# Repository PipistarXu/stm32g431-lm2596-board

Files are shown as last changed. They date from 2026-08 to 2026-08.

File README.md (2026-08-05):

# STM32G431 + LM2596 Custom Board

## Project Status
- PCB design completed
- Assembly not started yet

## Goals
- Build a custom control/power board based on STM32G431.
- Use LM2596 buck stage for stable DC conversion.
- Complete bring-up with safe current-limited power-on.

## Confirmed Hardware Decisions
- MCU: **STM32G431** (UFQFPN48 package)
- Buck IC: **LM2596S-ADJ**
- Schottky diode: **1N5822**
  - Polarity rule: **K (stripe) -> SW**, **A -> GND**
- Inductor: **CDRH127/LDNP-330MC**
  - 33uH, 12x12mm footprint, height ~8mm
- Small capacitors (SMD): 0603, X7R preferred
- R4 package: 0402 (1005 Metric), value TBD by final schematic intent

## Current Risks / Open Items
- [ ] Verify D2 pad net with multimeter (must be SW/GND as expected)
- [ ] Confirm 8mm inductor height clearance with enclosure/mechanics
- [ ] Confirm 220uF capacitor package availability (6.3x5.4 may be tight)
- [ ] Finalize R4 resistance value
- [ ] Prepare first power-on with current limit (0.1A~0.2A)

## Repository Layout
- `docs/`: notes, checklist, images
- `hardware/kicad/`: source schematic + PCB
- `hardware/fabrication/`: gerber, drill, BOM, pick-and-place
- `hardware/datasheets/`: key PDFs
- `firmware/`: future STM32 firmware

## First Bring-Up (Summary)
1. Visual inspection (orientation, bridges, polarity)
2. Resistance checks (VIN-GND, 5V-GND/3V3-GND)
3. Power from bench supply with 0.1A current limit
4. Verify LM2596 output and thermal behavior
5. Increase current limit gradually

## Notes
- UFQFPN48 is difficult for hand soldering; hot-air and flux are strongly recommended.
- Always trust actual net connectivity + multimeter over silkscreen when conflict exists.

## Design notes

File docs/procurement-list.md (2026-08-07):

# Procurement List (Current Draft)

## 1) Core ICs
- STM32G431 (UFQFPN48 package)
- LM2596S-ADJ
- 1N5822 (Schottky diode, DO-201 class)

## 2) Power Inductor
- Selected: **CDRH127/LDNP-330MC** (33uH, 12x12mm, H~8mm)

## 3) Capacitors (from current design snapshot)
- C1: 100nF, 0603, X7R
- C2: 0.47uF, 0603, X7R
- C3: 47uF, SMD electrolytic, low ESR
- C4: 100nF, 0603, X7R
- C5: 10nF, 0603, X7R
- C6: 100nF, 0603, X7R
- C7: 100nF, 0603, X7R
- C8: 100uF, SMD electrolytic, low ESR
- C9: 220uF, SMD electrolytic, low ESR
- C10: 100nF, 0603, X7R

## 4) Resistors
- R4 package: 0402 (1005 Metric), resistance value TBD
- Suggest stocking common debug values:
  - 0Ω
  - 100Ω
  - 10kΩ

## 5) Recommended Tools / Consumables
- Flux pen / solder paste
- Hot-air station
- Fine tweezers
- Multimeter
- Bench power supply with current limiting
- Optional oscilloscope (ripple/SW waveform check)

## 6) Pending Procurement Decisions
- Final R4 value after schematic intent confirmation
- Final electrolytic voltage rating vs actual VIN
- C9 package upsize if 6.3x5.4 sourcing is limited

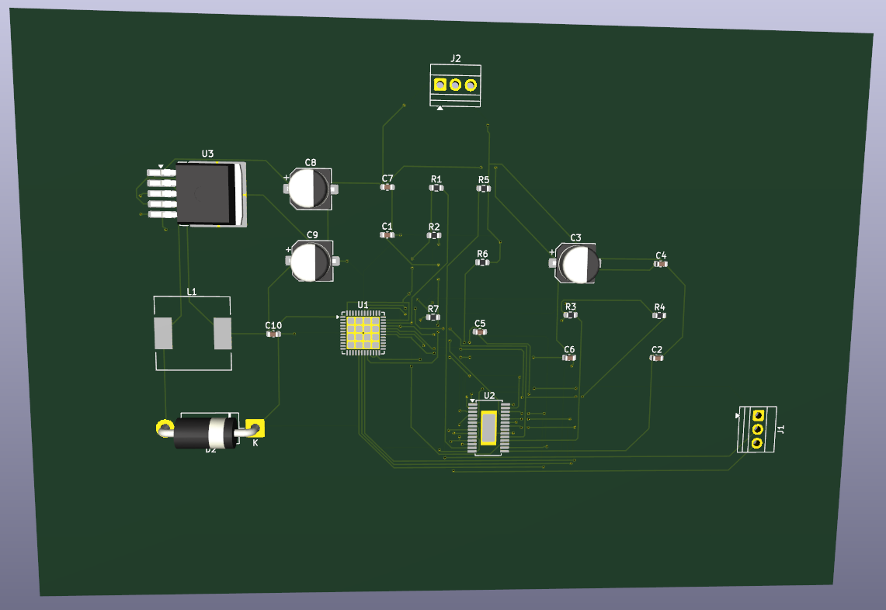
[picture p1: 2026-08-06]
docs/images/Screenshot 2026-08-05 223316.png

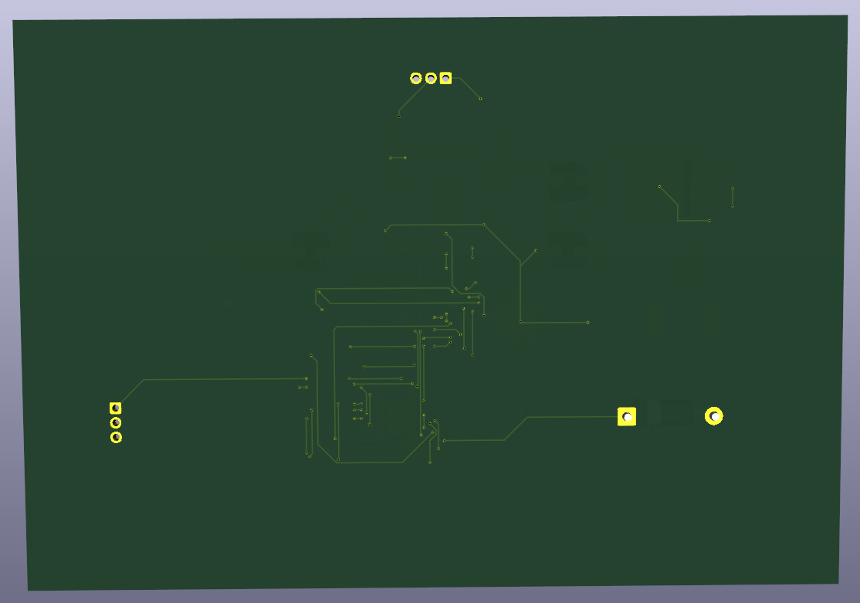
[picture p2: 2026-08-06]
docs/images/Screenshot 2026-08-05 223302.png

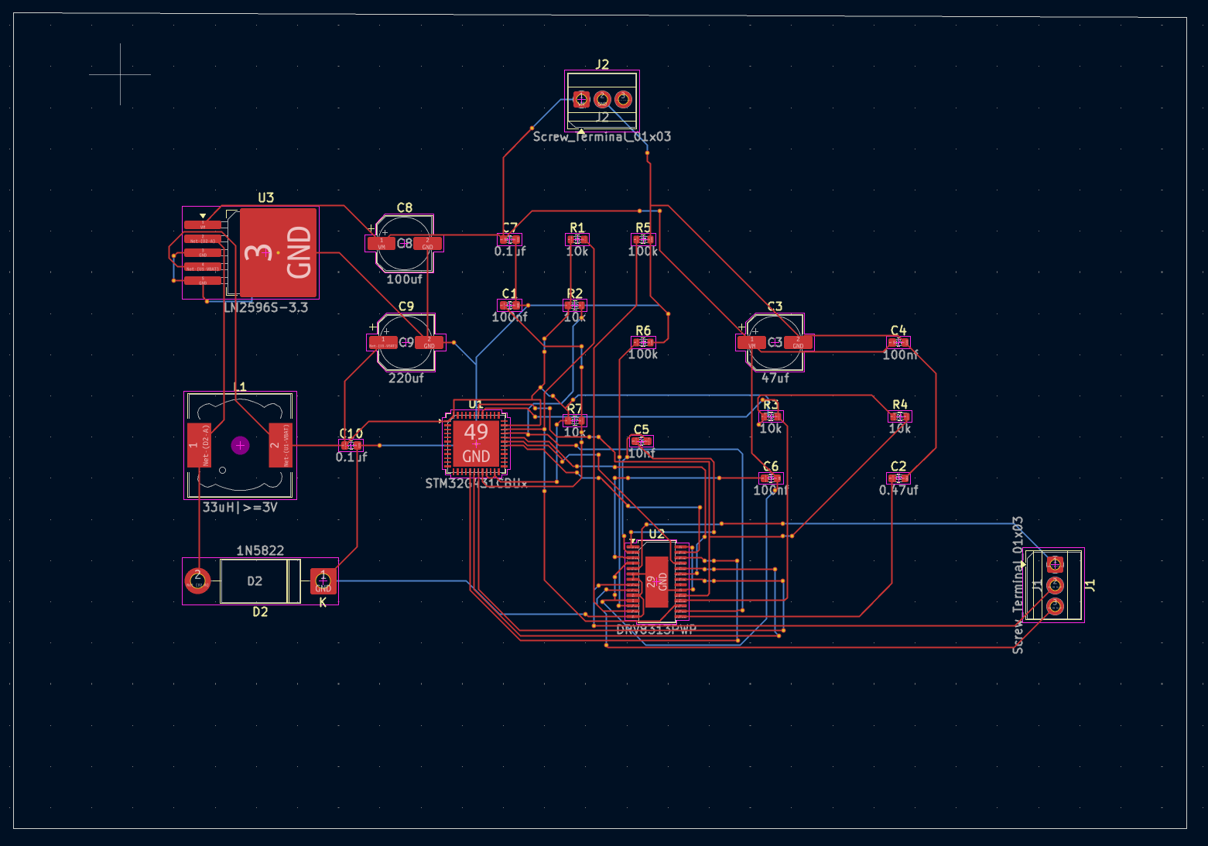
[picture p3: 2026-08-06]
docs/images/pcb_2d.png

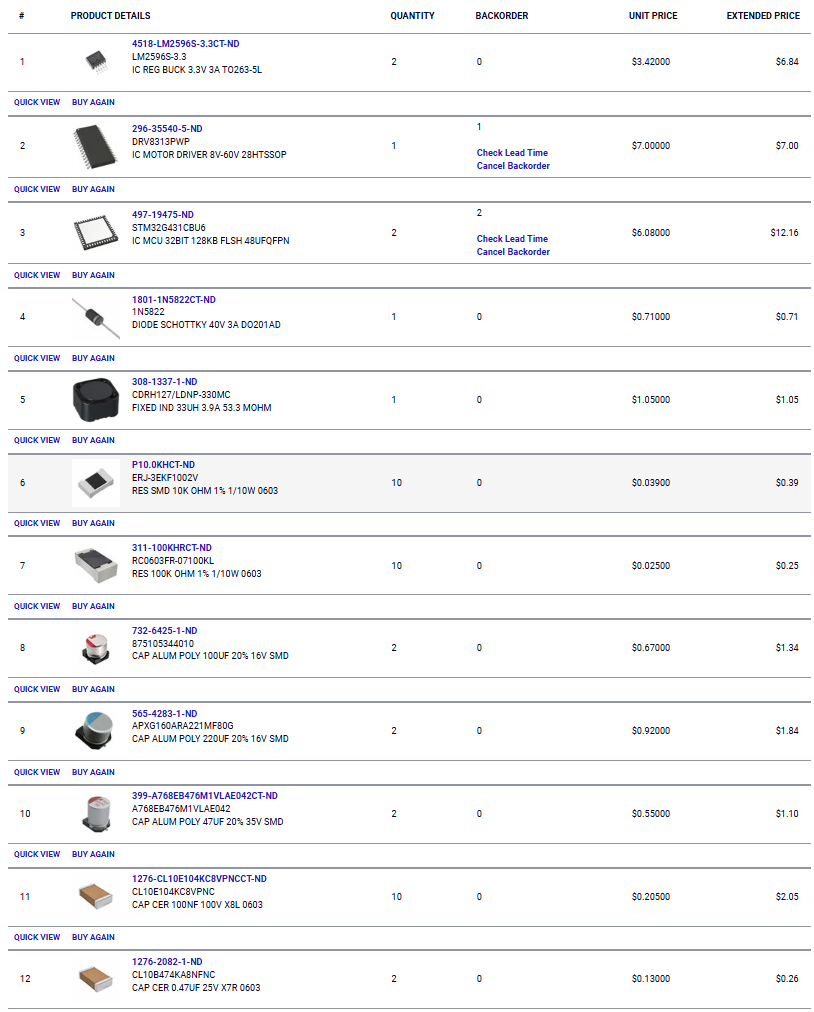
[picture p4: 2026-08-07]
docs/images/DigiKey_screenshot.png

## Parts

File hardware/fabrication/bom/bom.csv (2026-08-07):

Reference | Qty | Value | DNP | Exclude from BOM | Exclude from Board | Footprint | Datasheet | Check_prices | MANUFACTURER | MAXIMUM_PACKAGE_HEIGHT | MF | MP | Availability | Description | #
C1,C4,C6 | 3 | 100nf |  |  |  | Capacitor_SMD:C_0603_1608Metric |  |  |  |  |  |  |  | capacitor, US symbol | 1
C2 | 1 | 0.47uf |  |  |  | Capacitor_SMD:C_0603_1608Metric |  |  |  |  |  |  |  | capacitor, US symbol | 2
C3 | 1 | 47uf |  |  |  | Capacitor_SMD:CP_Elec_6.3x5.4 |  |  |  |  |  |  |  | capacitor, US symbol | 3
C5 | 1 | 10nf |  |  |  | Capacitor_SMD:C_0603_1608Metric |  |  |  |  |  |  |  | capacitor, US symbol | 4
C7,C10 | 2 | 0.1uf |  |  |  | Capacitor_SMD:C_0603_1608Metric |  |  |  |  |  |  |  | capacitor, US symbol | 5
C8 | 1 | 100uf |  |  |  | Capacitor_SMD:CP_Elec_6.3x5.4 |  |  |  |  |  |  |  | capacitor, US symbol | 6
C9 | 1 | 220uf |  |  |  | Capacitor_SMD:CP_Elec_6.3x5.4 |  |  |  |  |  |  |  | capacitor, US symbol | 7
D2 | 1 | 1N5822 |  |  |  | Diode_THT:D_DO-201AD_P15.24mm_Horizontal | http://www.vishay.com/docs/88526/1n5820.pdf |  |  |  |  |  |  | 40V 3A Schottky Barrier Rectifier Diode, DO-201AD | 8
J1,J2 | 2 | Screw_Terminal_01x03 |  |  |  | TerminalBlock:TerminalBlock_Xinya_XY308-2.54-3P_1x03_P2.54mm_Horizontal |  |  |  |  |  |  |  | Generic screw terminal, single row, 01x03, script generated (kicad-library-utils/schlib/autogen/connector/) | 9
L1 | 1 | 33uH|>=3V |  |  |  | Inductor_SMD:L_12x12mm_H6mm |  |  |  |  |  |  |  | Inductor | 10
R1,R2,R3,R4,R7 | 5 | 10k |  |  |  | Resistor_SMD:R_0603_1608Metric |  |  |  |  |  |  |  | Resistor | 11
R5,R6 | 2 | 100k |  |  |  | Resistor_SMD:R_0603_1608Metric |  |  |  |  |  |  |  | Resistor | 12
U1 | 1 | STM32G431CBUx |  |  |  | Package_DFN_QFN:QFN-48-1EP_7x7mm_P0.5mm_EP5.6x5.6mm | https://www.st.com/resource/en/datasheet/stm32g431cb.pdf |  |  |  |  |  |  | STMicroelectronics Arm Cortex-M4 MCU, 128KB flash, 32KB RAM, 170 MHz, 1.71-3.6V, 42 GPIO, UFQFPN48 | 13
U2 | 1 | DRV8313PWP |  |  |  | Package_SO:HTSSOP-28-1EP_4.4x9.7mm_P0.65mm_EP2.75x6.2mm |  | https://www.snapeda.com/parts/DRV8313PWP/Texas+Instruments/view-part/?ref=eda | Texas Instruments | 1.2 mm | Texas Instruments | DRV8313PWP | In Stock | 65-V max 3-A peak 3-phase motor driver with integrated FETs | 14
U3 | 1 | LM2596S-3.3 |  |  |  | Package_TO_SOT_SMD:TO-263-5_TabPin3 | http://www.ti.com/lit/ds/symlink/lm2596.pdf |  |  |  |  |  |  | 3.3V 3A Step-Down Voltage Regulator, TO-263 | 15

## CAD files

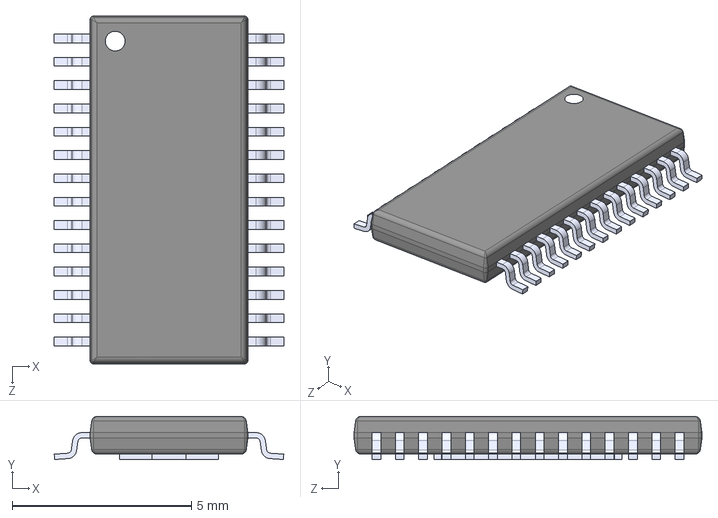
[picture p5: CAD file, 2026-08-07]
hardware/ kicad/ libraries/DRV8313PWP.step
6.40 x 1.20 x 9.70 mm

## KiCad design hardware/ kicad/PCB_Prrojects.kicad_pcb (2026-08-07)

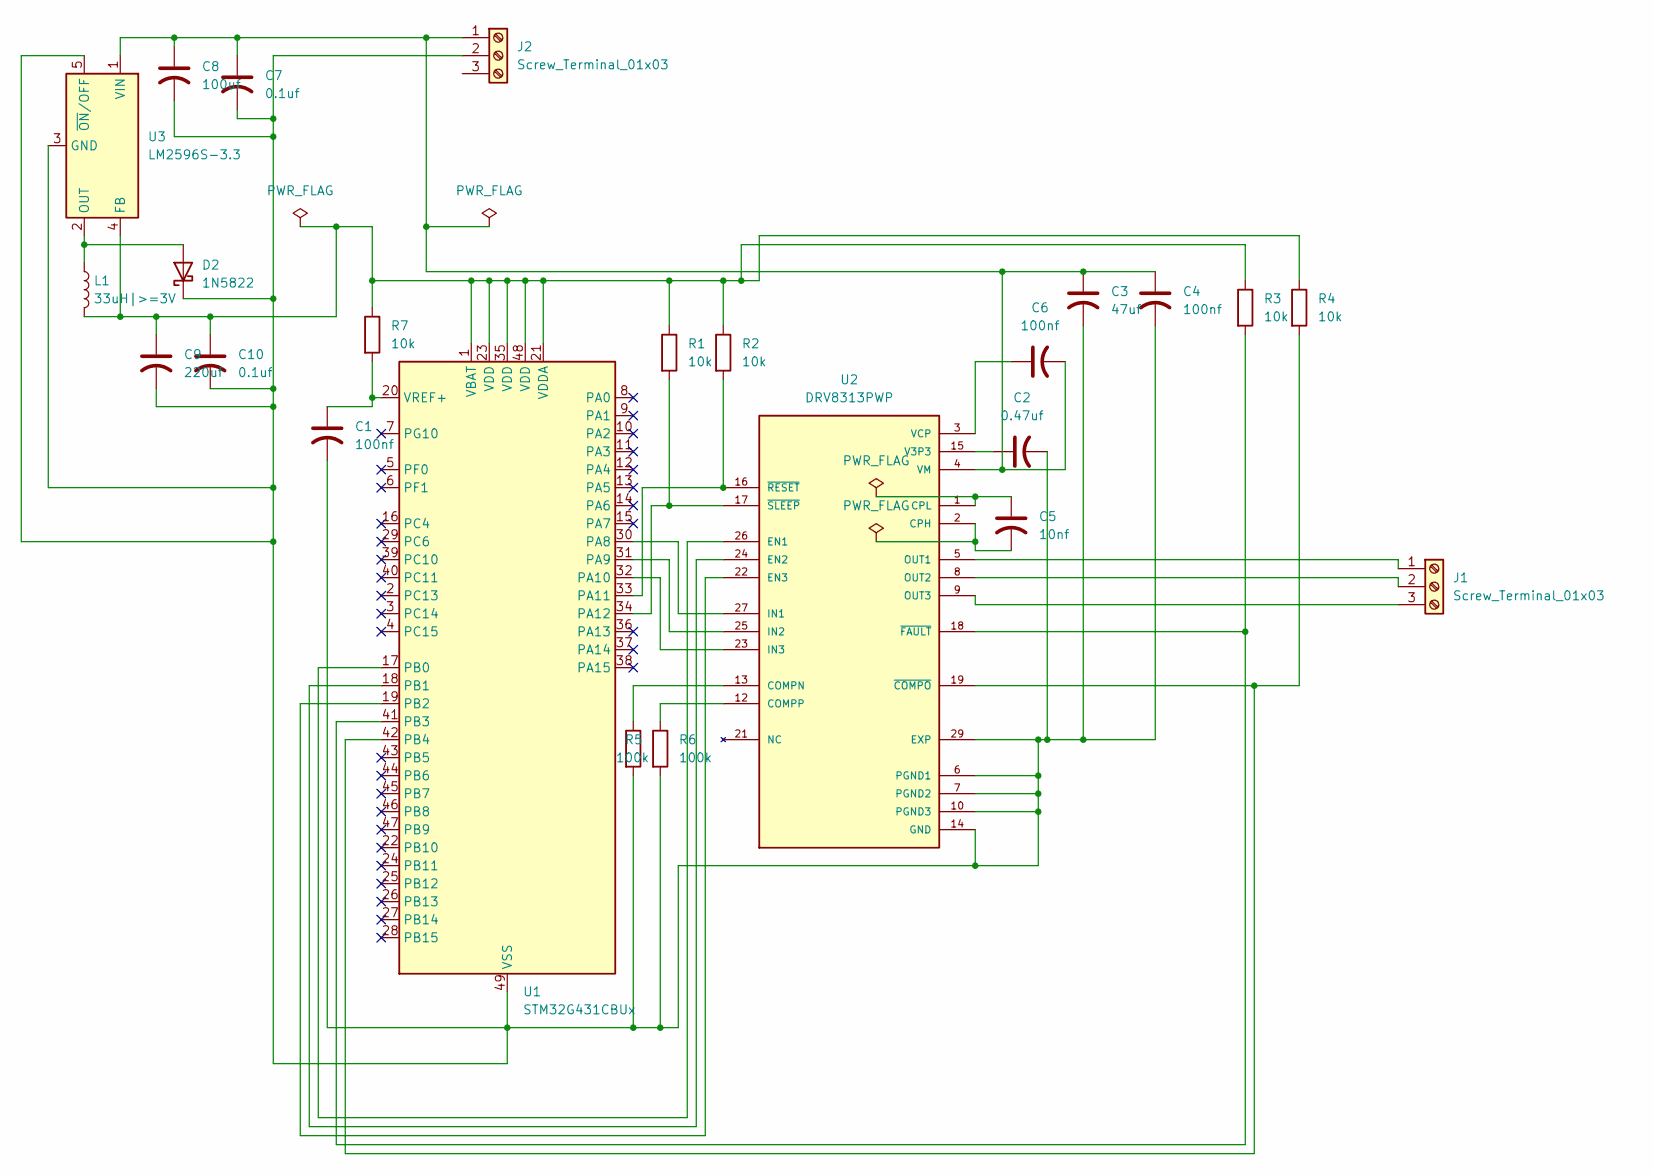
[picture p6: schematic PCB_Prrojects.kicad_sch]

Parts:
C1, C4, C6: 100nf; C_0603_1608Metric
C2: 0.47uf; C_0603_1608Metric
C3: 47uf; CP_Elec_6.3x5.4
C5: 10nf; C_0603_1608Metric
C7, C10: 0.1uf; C_0603_1608Metric
C8: 100uf; CP_Elec_6.3x5.4
C9: 220uf; CP_Elec_6.3x5.4
D2: 1N5822; D_DO-201AD_P15.24mm_Horizontal
J1, J2: Screw_Terminal_01x03; TerminalBlock_Xinya_XY308-2.54-3P_1x03_P2.54mm_Horizontal
L1: 33uH|>=3V; L_12x12mm_H6mm
R1, R2, R3, R4, R7: 10k; R_0603_1608Metric
R5, R6: 100k; R_0603_1608Metric
U1: STM32G431CBUx; QFN-48-1EP_7x7mm_P0.5mm_EP5.6x5.6mm
U2: DRV8313PWP; HTSSOP-28-1EP_4.4x9.7mm_P0.65mm_EP2.75x6.2mm; PARTREV D
U3: LM2596S-3.3; TO-263-5_TabPin3

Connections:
GND: C1.2, C2.2, C3.2, C4.2, C7.2, C8.2, C9.2, C10.2, D2.1 (K), J2.2, R5.2, R6.2, U1.49 (VSS), U2.6 (PGND1), U2.7 (PGND2), U2.10 (PGND3), U2.14 (GND), U2.20 (GND), U2.28 (GND), U2.29 (EXP), U3.3 (GND), U3.5 (~ON/OFF)
unnamed: D2.2 (A), L1.1, U3.2 (OUT)
unnamed: J1.1, U2.5 (OUT1)
unnamed: J1.2, U2.8 (OUT2)
unnamed: J1.3, U2.9 (OUT3)
unnamed: U1.30 (PA8), U2.27 (IN1)
unnamed: U1.31 (PA9), U2.25 (IN2)
unnamed: U1.32 (PA10), U2.23 (IN3)
unnamed: R2.2, U1.33 (PA11), U2.16 (~RESET)
unnamed: R1.2, U1.34 (PA12), U2.17 (~SLEEP)
unnamed: U1.17 (PB0), U2.26 (EN1)
unnamed: U1.18 (PB1), U2.24 (EN2)
unnamed: U1.19 (PB2), U2.22 (EN3)
unnamed: R3.2, U1.41 (PB3), U2.18 (~FAULT)
unnamed: R4.2, U1.42 (PB4), U2.19 (~COMPO)
unnamed: C9.1, C10.1, L1.2, R1.1, R2.1, R3.1, R4.1, R7.1, U1.1 (VBAT), U1.21 (VDDA), U1.23 (VDD), U1.35 (VDD), U1.48 (VDD), U3.4 (FB)
unnamed: C1.1, R7.2, U1.20 (VREF+)
unnamed: R5.1, U2.13 (COMPN)
unnamed: R6.1, U2.12 (COMPP)
unnamed: C5.2, U2.2 (CPH)
unnamed: C5.1, U2.1 (CPL)
unnamed: C2.1, U2.15 (V3P3)
unnamed: C6.1, U2.3 (VCP)
VM: C3.1, C4.1, C6.2, C7.1, C8.1, J2.1, U2.4 (VM), U2.11 (VM), U3.1 (VIN)

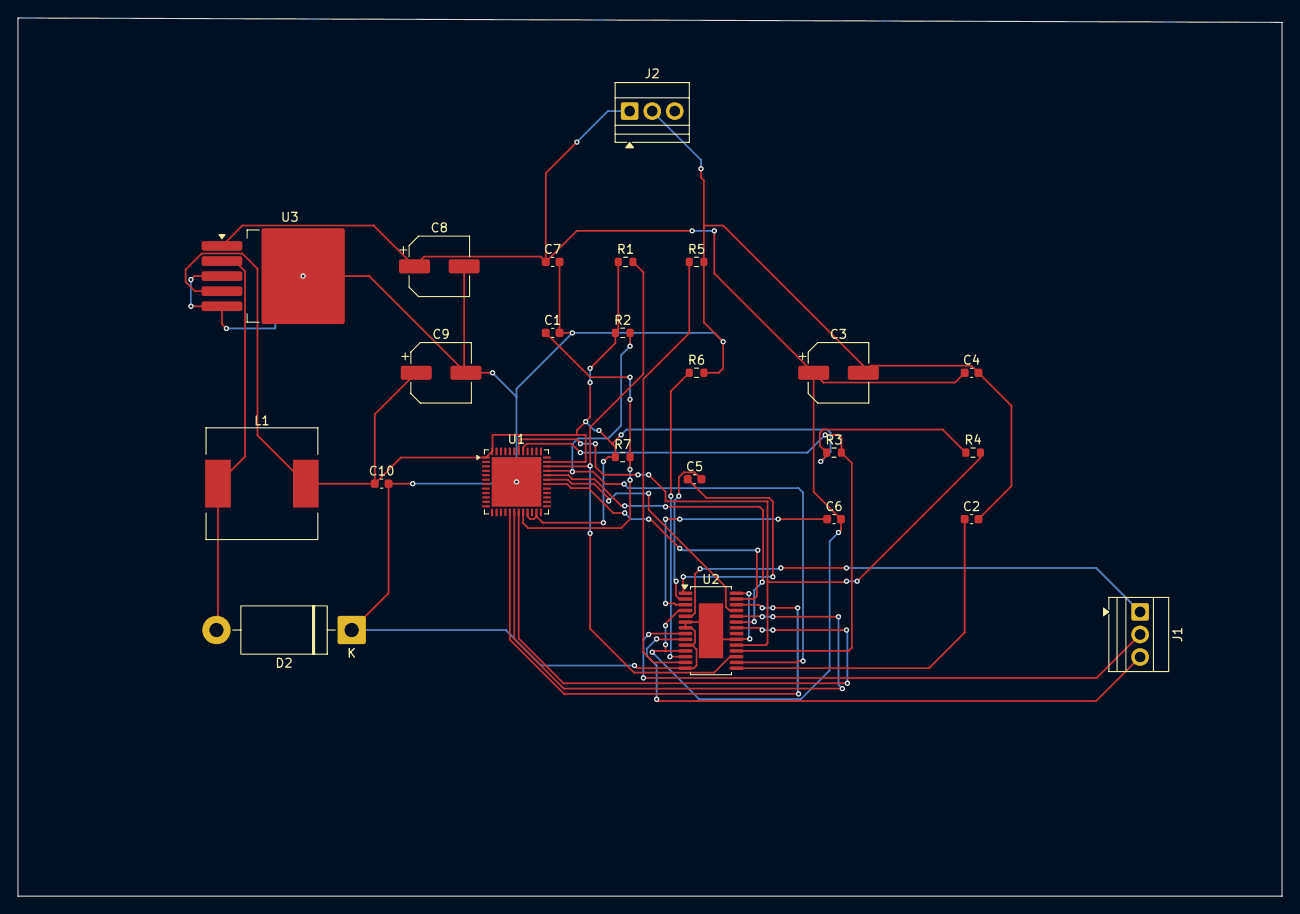
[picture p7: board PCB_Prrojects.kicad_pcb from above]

Board: 2 copper layers, 142.5 x 99.0 mm, 24 parts (0 on the bottom side), 24 nets.

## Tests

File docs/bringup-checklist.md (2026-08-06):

# Bring-Up Checklist (STM32G431 + LM2596)

## A. Pre-Solder Checklist
- [ ] All parts received and matched with BOM values
- [ ] Verify package compatibility (especially inductor and electrolytics)
- [ ] Confirm orientation marks for:
  - [ ] STM32 pin-1
  - [ ] 1N5822 stripe side
  - [ ] Electrolytic capacitor polarity
- [ ] Flux, paste, tweezers, hot-air station ready

## B. Post-Solder Visual Inspection
- [ ] No solder bridges on MCU pins
- [ ] Exposed pad not over-pasted (no floating package)
- [ ] Diode direction correct (K->SW, A->GND)
- [ ] Electrolytic caps polarity correct
- [ ] Inductor seated and aligned
- [ ] No missing passives

## C. Multimeter Checks (Power OFF)
- [ ] VIN to GND resistance (not near-short)
- [ ] 5V/3V3 to GND resistance (not near-short)
- [ ] Continuity check D2 pad-to-net:
  - [ ] Stripe pad continuity to SW node
  - [ ] Other pad continuity to GND

## D. First Power-On (Bench Supply)
- [ ] Set current limit to 0.1A
- [ ] Start with intended VIN (or lower safe VIN if design allows)
- [ ] Confirm current does not instantly clamp hard
- [ ] Measure LM2596 output voltage
- [ ] If normal, raise current limit gradually to 0.2A / 0.3A
- [ ] Check temperature of LM2596, diode, inductor

## E. MCU Bring-Up
- [ ] Confirm 3V3 stable
- [ ] SWD connection recognized
- [ ] Flash minimal test firmware (blinky/UART log)
- [ ] Verify reset/boot behavior

## F. If Abnormal
- [ ] Immediate power-off
- [ ] Re-check shorts and polarity
- [ ] Inspect suspicious joints with magnification
- [ ] Reflow MCU/diode region if needed

  1. Continuity/short checks
  2. Low-current power-on
  3. Verify output rails
  4. Thermal check by touch/IR
  5. Increase limit gradually

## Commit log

2026-08-06 Rename Screenshot 2026-08-05 215720.png to pcb_2d.png
2026-08-06 Rename Screenshot 2026-08-05 223316.png to pcb_3d.png
